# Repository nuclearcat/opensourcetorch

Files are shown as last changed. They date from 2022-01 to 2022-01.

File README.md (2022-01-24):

Opensource programmable... torch? light? flashlight? I dont know, but it is funny and i like it.

We have onboard:
3xRGB(parallel) light, indicator light, accelerometer, illumination sensor, USB-Serial (CH340) for debug, lithium battery charger.

Example applications: coming soon

Read ERRATA first, if you want to make your own!

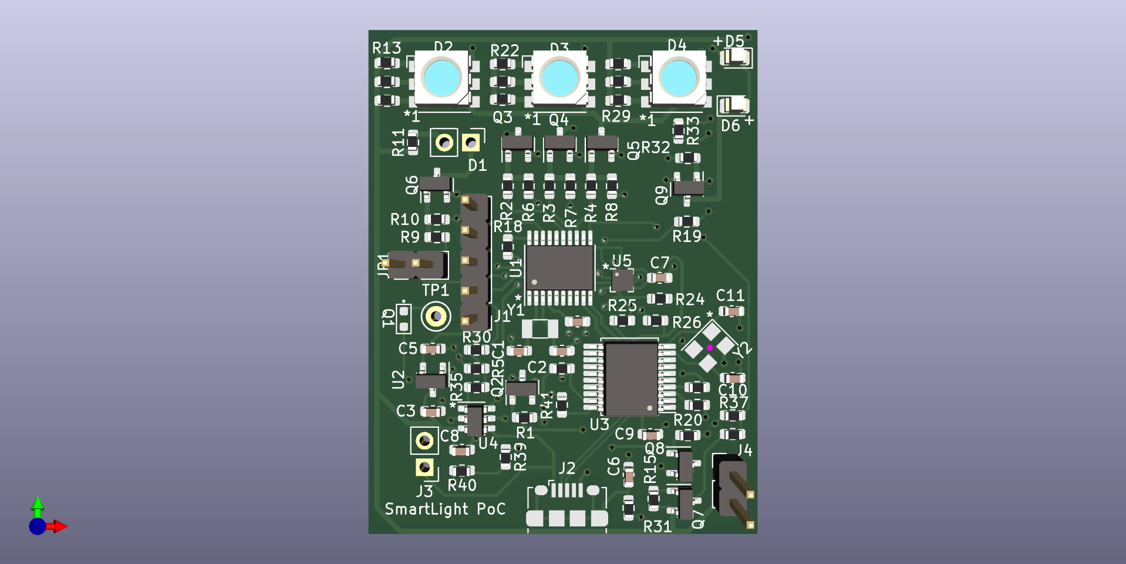
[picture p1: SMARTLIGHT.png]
v1 prototype


ERRATA in v1.0   
* 32Khz oscillator on MCU not starting reliably. (Might be software issue.)

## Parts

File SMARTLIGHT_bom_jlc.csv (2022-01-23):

Comment | Designator | Footprint | LCSC Part #
15pf | C1,C2,C6 | C_0603_1608Metric | C1644
1u | C3,C4,C5,C7,C9 | C_0603_1608Metric | C15849
10u | C8 | C_0603_1608Metric | C19702
12p | C10,C11 | C_0603_1608Metric | C38523
MHP5050RGBDT | D2,D3,D4 | MHP5050RGBDT | C409780
RED | D5,D6 | LED_0805_2012Metric | C138549
USB_B_Micro | J2 | USB_Micro-B_Amphenol_10118194_Horizontal | C132563
ALS-PT19 | Q1 | ALS-PT19 | C146233
YJL3400A | Q2,Q3,Q4,Q5,Q6,Q8,Q9 | SOT-23 | C699302
AO3401A | Q7 | SOT-23 | C15127
10k | R1,R5,R6,R7,R8,R10,R15,R16,R17,R20,R25,R26,R30,R31,R32,R34,R35,R39,R41 | R_0603_1608Metric | C25804
100 | R2,R3,R4,R9,R18,R19,R37,R38 | R_0603_1608Metric | C22775
10 | R11,R12,R13,R14,R21,R22,R23,R27,R28,R29,R33 | R_0603_1608Metric | C22859
0 | R40 | R_0603_1608Metric | C21189
STM32G030F6Px | U1 | TSSOP-20_4.4x6.5mm_P0.65mm | C529330
XC6206P332MR | U2 | SOT-23 | C5446
CH340T | U3 | SSOP-20_5.3x7.2mm_P0.65mm | C8689
FM4057S42 | U4 | SOT-23-6 | C841287
KX022-1020 | U5 | LGA-12_2x2mm_P0.5mm | C694095
Crystal | Y1 | Crystal_SMD_3215-2Pin_3.2x1.5mm | C32346
X322512MSB4SI | Y2 | Oscillator_SMD_SeikoEpson_SG8002CE-4Pin_3.2x2.5mm | C9002

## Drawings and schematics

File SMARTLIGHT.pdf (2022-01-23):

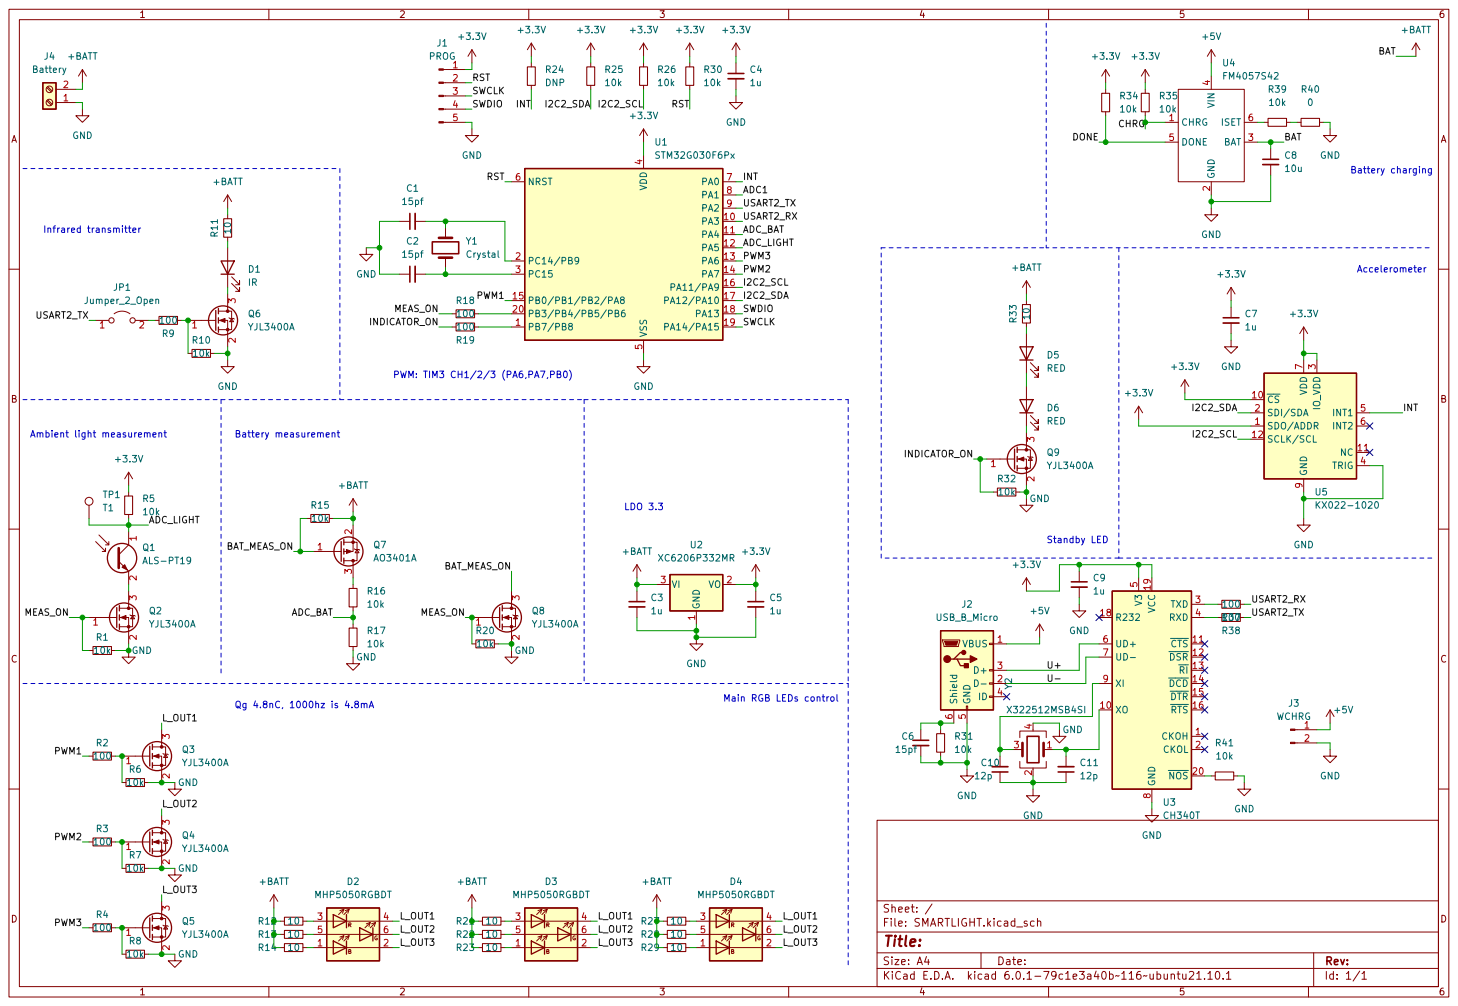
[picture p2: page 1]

1 VO 2 VI 3 U2 XC6206P332MR GND GND

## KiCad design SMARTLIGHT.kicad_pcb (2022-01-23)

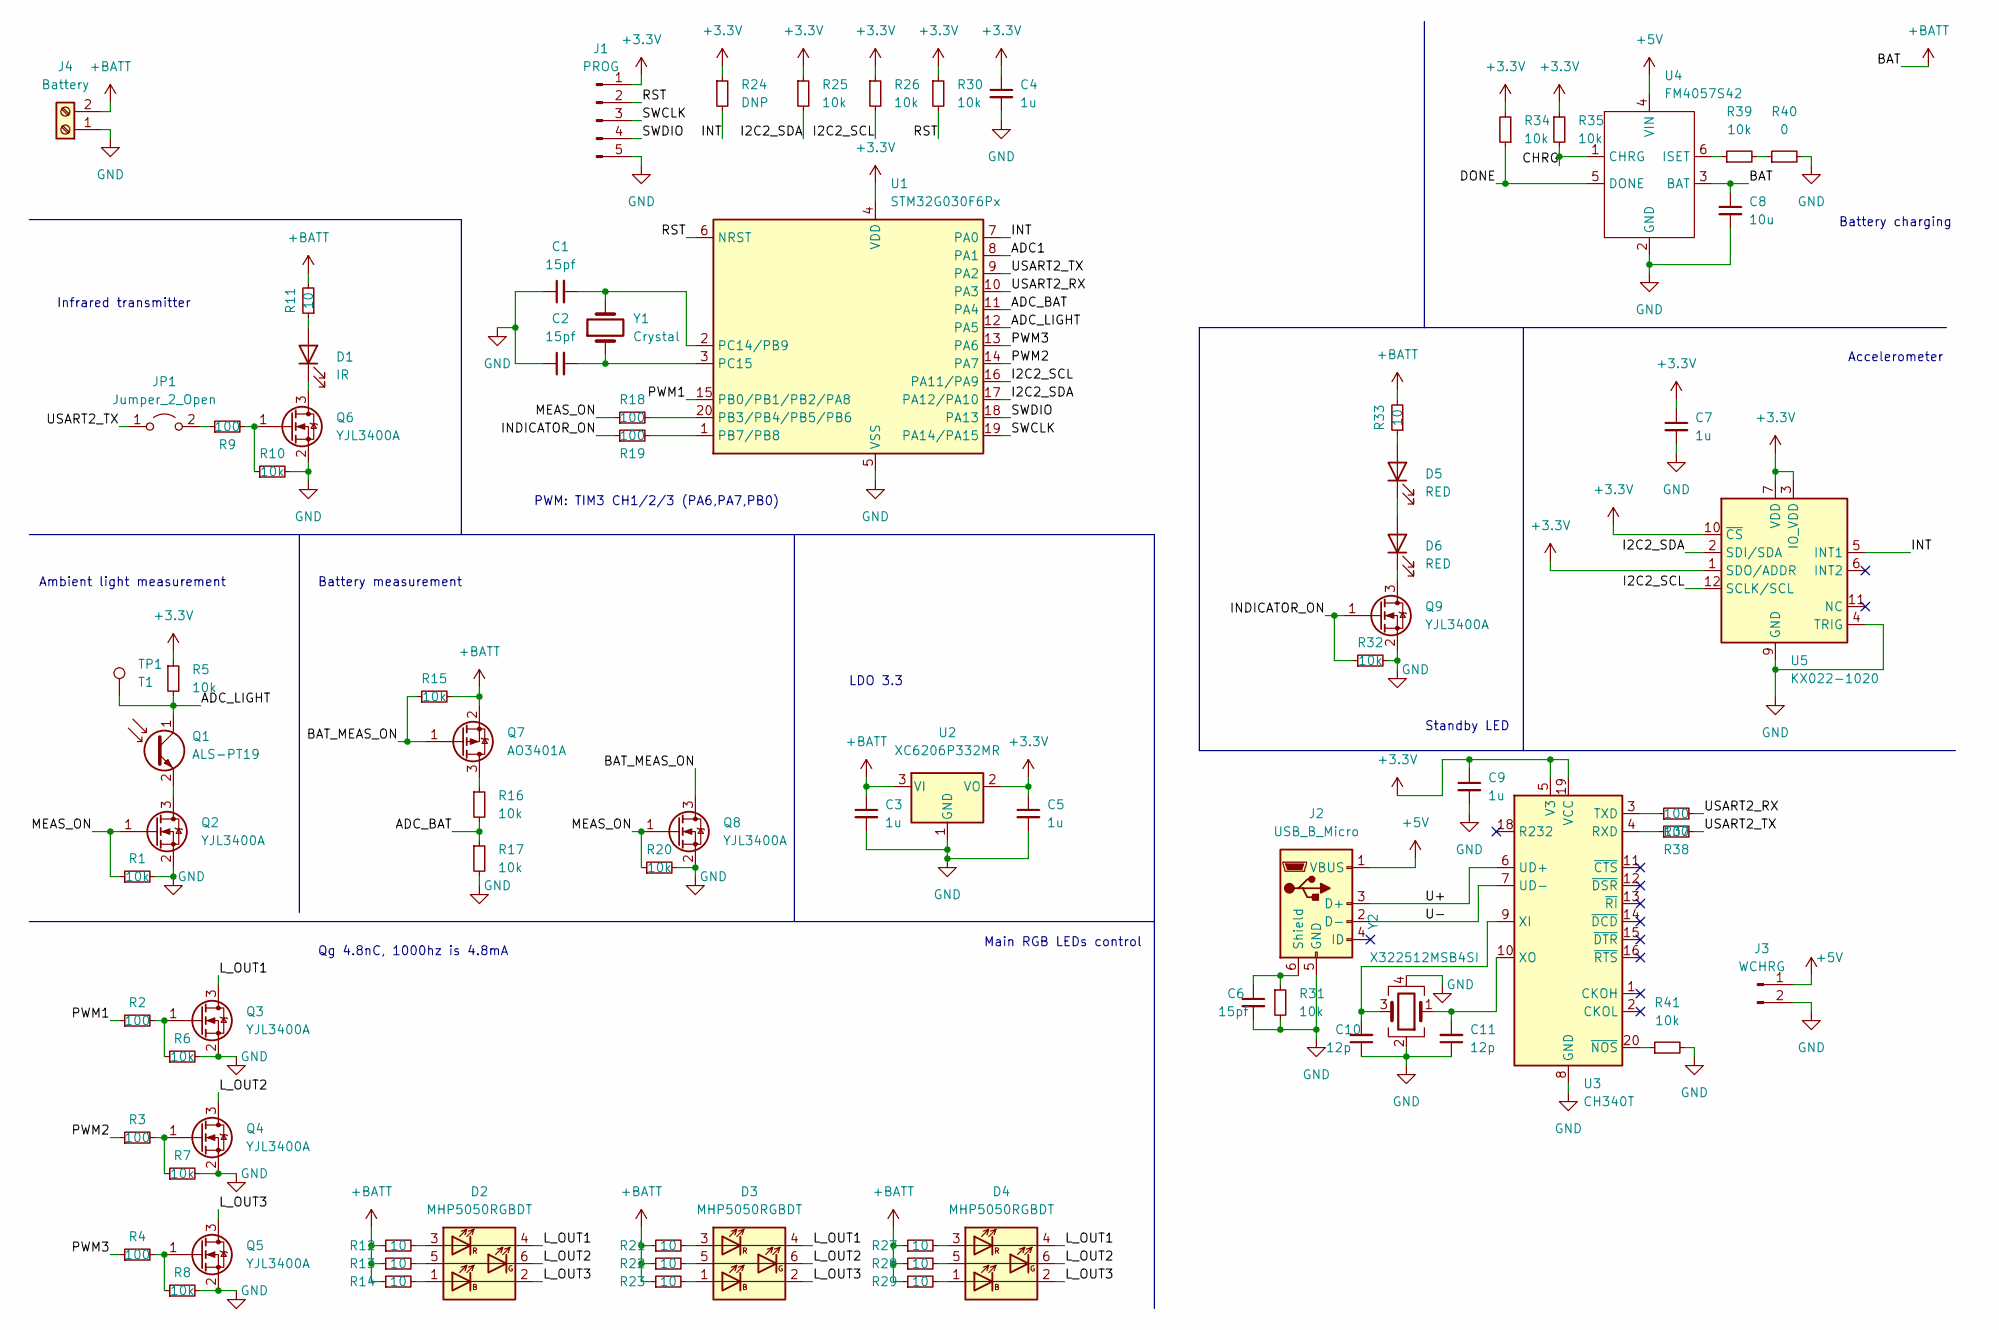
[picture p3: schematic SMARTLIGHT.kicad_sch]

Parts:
C1, C2, C6: 15pf; C_0603_1608Metric; LCSC PN C1644
C3, C4, C5, C7, C9: 1u; C_0603_1608Metric; LCSC PN C15849
C8: 10u; C_0603_1608Metric; LCSC PN C19702
C10, C11: 12p; C_0603_1608Metric; LCSC PN C38523
D1: IR; PinHeader_1x02_P2.54mm_Vertical
D2, D3, D4: MHP5050RGBDT; LCSC PN C409780
D5, D6: RED; LED_0805_2012Metric; LCSC PN C138549
J1: PROG; PinHeader_1x05_P2.54mm_Vertical
J2: USB_B_Micro; USB_Micro-B_Amphenol_10118194_Horizontal; LCSC PN C132563
J3: WCHRG; PinHeader_1x02_P2.54mm_Vertical
J4: Battery; PinHeader_1x02_P2.54mm_Vertical
JP1: Jumper_2_Open; PinHeader_1x02_P2.54mm_Vertical
Q1: ALS-PT19; LCSC PN C146233
Q2, Q3, Q4, Q5, Q6, Q8, Q9: YJL3400A; SOT-23; LCSC PN C699302
Q7: AO3401A; SOT-23; LCSC PN C15127
R1, R5, R6, R7, R8, R10, R15, R16, R17, R20, R25, R26, R30, R31, R32, R34, R35, R39, R41: 10k; R_0603_1608Metric; LCSC PN C25804
R2, R3, R4, R9, R18, R19, R37, R38: 100; R_0603_1608Metric; LCSC PN C22775
R11, R12, R13, R14, R21, R22, R23, R27, R28, R29, R33: 10; R_0603_1608Metric; LCSC PN C22859
R24: DNP; R_0603_1608Metric
R40: 0; R_0603_1608Metric; LCSC PN C21189
TP1: T1; TestPoint_Keystone_5000-5004_Miniature
U1: STM32G030F6Px; TSSOP-20_4.4x6.5mm_P0.65mm; LCSC PN C529330
U2: XC6206P332MR; SOT-23; LCSC PN C5446
U3: CH340T; SSOP-20_5.3x7.2mm_P0.65mm; LCSC PN C8689
U4: FM4057S42; SOT-23-6; LCSC PN C841287
U5: KX022-1020; LGA-12_2x2mm_P0.5mm; LCSC PN C694095
Y1: Crystal; Crystal_SMD_3215-2Pin_3.2x1.5mm; LCSC PN C32346
Y2: X322512MSB4SI; Oscillator_SMD_SeikoEpson_SG8002CE-4Pin_3.2x2.5mm; LCSC PN C9002

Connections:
+3V3: C4.1, C5.1, C7.1, C9.1, J1.1, R5.1, R24.1, R25.1, R26.1, R30.1, R34.2, R35.1, U1.4 (VDD), U2.2 (VO), U3.5 (V3), U3.19 (VCC), U5.1 (SDO/ADDR), U5.3 (IO_VDD), U5.7 (VDD), U5.10 (~CS)
+5V: J2.1 (VBUS), J3.1, U4.4 (VIN)
+BATT: C3.1, C8.1, J4.2, Q7.2 (S), R11.2, R12.1, R13.1, R14.1, R15.2, R21.1, R22.1, R23.1, R27.1, R28.1, R29.1, R33.2, U2.3 (VI), U4.3 (BAT)
/ADC1: U1.8 (PA1)
/ADC_BAT: R16.2, R17.1, U1.11 (PA4)
/ADC_LIGHT: Q1.1 (C), R5.2, TP1.1, U1.12 (PA5)
/BAT_MEAS_ON: Q7.1 (G), Q8.3 (D), R15.1
/CHRG: R35.2, U4.1 (CHRG)
/DONE: R34.1, U4.5 (DONE)
/I2C2_SCL: R26.2, U1.16 (PA11/PA9), U5.12 (SCLK/SCL)
/I2C2_SDA: R25.2, U1.17 (PA12/PA10), U5.2 (SDI/SDA)
/INDICATOR_ON: Q9.1 (G), R19.1, R32.1
/INT: R24.2, U1.7 (PA0), U5.5 (INT1)
/L_OUT1: D2.4 (KR), D3.4 (KR), D4.4 (KR), Q3.3 (D)
/L_OUT2: D2.6 (KR), D3.6 (KR), D4.6 (KR), Q4.3 (D)
/L_OUT3: D2.2 (KB), D3.2 (KB), D4.2 (KB), Q5.3 (D)
/MEAS_ON: Q2.1 (G), Q8.1 (G), R1.1, R18.1, R20.1
/PWM1: R2.1, U1.15 (PB0/PB1/PB2/PA8)
/PWM2: R3.1, U1.14 (PA7)
/PWM3: R4.1, U1.13 (PA6)
/RST: J1.2, R30.2, U1.6 (NRST)
/SWCLK: J1.3, U1.19 (PA14/PA15)
/SWDIO: J1.4, U1.18 (PA13)
/U+: J2.3 (D+), U3.6 (UD+)
/U-: J2.2 (D-), U3.7 (UD-)
/USART2_RX: R37.2, U1.10 (PA3)
/USART2_TX: JP1.1 (A), R38.2, U1.9 (PA2)
GND: C1.1, C2.1, C3.2, C4.2, C5.2, C6.2, C7.2, C8.2, C9.2, C10.1, C11.1, J1.5, J2.5 (GND), J3.2, J4.1, Q2.2 (S), Q3.2 (S), Q4.2 (S), Q5.2 (S), Q6.2 (S), Q8.2 (S), Q9.2 (S), R1.2, R6.2, R7.2, R8.2, R10.2, R17.2, R20.2, R31.2, R32.2, R40.2, R41.2, U1.5 (VSS), U2.1 (GND), U3.8 (GND), U4.2 (GND), U5.4 (TRIG), U5.8 (GND), U5.9 (GND), Y2.2, Y2.4
unnamed: C1.2, U1.2 (PC14/PB9), Y1.2
unnamed: C2.2, U1.3 (PC15), Y1.1
unnamed: C6.1, J2.6 (Shield), R31.1
unnamed: C10.2, U3.9 (XI), Y2.3
unnamed: C11.2, U3.10 (XO), Y2.1
unnamed: D1.1 (K), Q6.3 (D)
unnamed: D1.2 (A), R11.1
unnamed: D2.1 (AB), R14.2
unnamed: D2.3 (AR), R12.2
unnamed: D2.5 (AG), R13.2
unnamed: D3.1 (AB), R23.2
unnamed: D3.3 (AR), R21.2
unnamed: D3.5 (AG), R22.2
unnamed: D4.1 (AB), R29.2
unnamed: D4.3 (AR), R27.2
unnamed: D4.5 (AG), R28.2
unnamed: D5.1 (K), D6.2 (A)
unnamed: D5.2 (A), R33.1
unnamed: D6.1 (K), Q9.3 (D)
unnamed: JP1.2 (B), R9.1
unnamed: Q1.2 (E), Q2.3 (D)
unnamed: Q3.1 (G), R2.2, R6.1
unnamed: Q4.1 (G), R3.2, R7.1
unnamed: Q5.1 (G), R4.2, R8.1
unnamed: Q6.1 (G), R9.2, R10.1
unnamed: Q7.3 (D), R16.1
unnamed: R18.2, U1.20 (PB3/PB4/PB5/PB6)
unnamed: R19.2, U1.1 (PB7/PB8)
unnamed: R37.1, U3.3 (TXD)
unnamed: R38.1, U3.4 (RXD)
unnamed: R39.1, U4.6 (ISET)
unnamed: R39.2, R40.1
unnamed: R41.1, U3.20 (~NOS)

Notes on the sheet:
Ambient light measurement
Infrared transmitter
Accelerometer
Standby LED
PWM: TIM3 CH1/2/3 (PA6,PA7,PB0)
Battery measurement
Qg 4.8nC, 1000hz is 4.8mA
Battery charging
Main RGB LEDs control
LDO 3.3

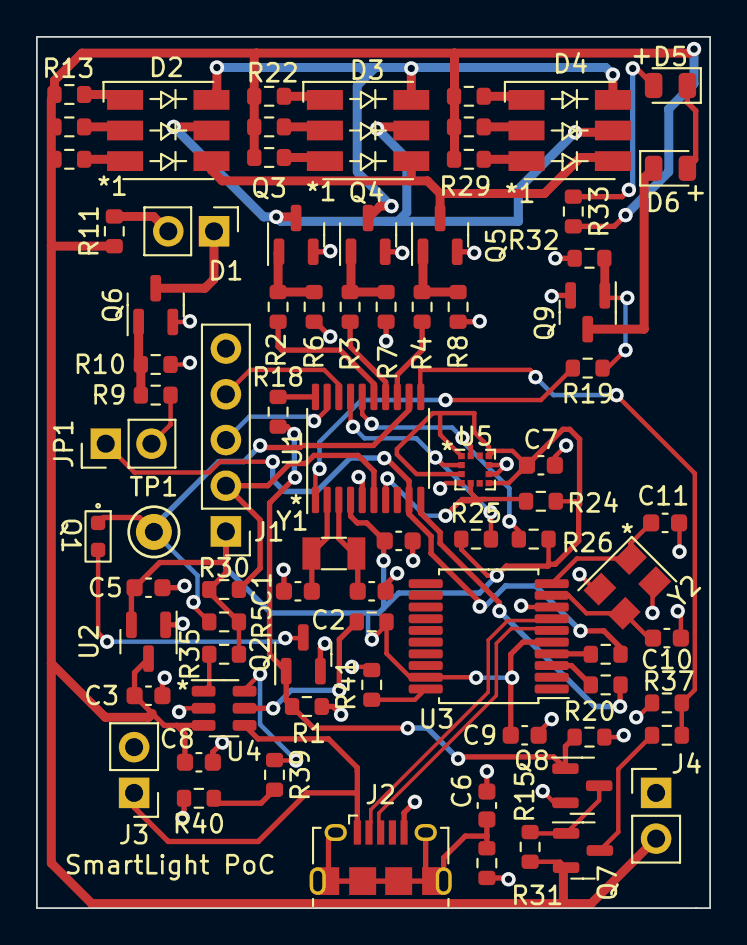
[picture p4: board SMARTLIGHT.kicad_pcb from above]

Board: 2 copper layers, 37.4 x 48.4 mm, 79 parts (0 on the bottom side), 60 nets.

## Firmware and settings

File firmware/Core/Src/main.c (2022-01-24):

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
/* Includes ------------------------------------------------------------------*/
#include "main.h"

ADC_HandleTypeDef hadc1;

I2C_HandleTypeDef hi2c2;

RTC_HandleTypeDef hrtc;

TIM_HandleTypeDef htim1;
TIM_HandleTypeDef htim3;

UART_HandleTypeDef huart2;

void SystemClock_Config(void);
static void MX_GPIO_Init(void);
static void MX_ADC1_Init(void);
static void MX_I2C2_Init(void);
static void MX_RTC_Init(void);
static void MX_USART2_UART_Init(void);
static void MX_TIM1_Init(void);
static void MX_TIM3_Init(void);
/* USER CODE BEGIN 0 */

int kx022_readregs(int addr, uint8_t * data, int len) {
  int status = HAL_I2C_Mem_Read(&hi2c2, KX022_I2C_ADDRESS, addr, I2C_MEMADD_SIZE_8BIT, data, len, 10000);
  if (status != HAL_OK)
    return 1;
  else
    return 0;
}

int kx022_writeregs(int addr, uint8_t * data, int len) {
  int status =  HAL_I2C_Mem_Write(&hi2c2, (uint16_t)KX022_I2C_ADDRESS, addr, I2C_MEMADD_SIZE_8BIT, (uint8_t *)data, len, 10000);
  if (status != HAL_OK)
    return 1;
  else
    return 0;
}

int16_t kx022_getAccAxis(uint8_t addr) {
    int16_t acc;
    uint8_t res[2];
 
    kx022_readregs(addr, res, 2);
    acc = ((res[1] << 8) | res[0]);
    return acc;
}

int16_t kx022_getAccX() {
    return (kx022_getAccAxis(KX022_XOUT_L));
}
 
int16_t kx022_getAccY() {
    return (kx022_getAccAxis(KX022_YOUT_L));
}
 
int16_t kx022_getAccZ() {
    return (kx022_getAccAxis(KX022_ZOUT_L));
}


void test_measure_light(void) {
  ADC_ChannelConfTypeDef sConfig = {0};
  char buffer[32] = { 0 };
  
  // Make sure other lights off to not interfere
  __HAL_TIM_SET_COMPARE(&htim3, TIM_CHANNEL_1, 0);
  __HAL_TIM_SET_COMPARE(&htim3, TIM_CHANNEL_2, 0);
  __HAL_TIM_SET_COMPARE(&htim3, TIM_CHANNEL_3, 0);

  // Power on measurement circuit (battery and light)
  HAL_GPIO_WritePin(MEAS_CTRL_PORT, MEAS_CTRL_PIN, GPIO_PIN_SET);
  // Delay to settle down
  HAL_Delay(1);

  sConfig.Channel = ADC_CHANNEL_5;
  sConfig.Rank = ADC_REGULAR_RANK_1;
  sConfig.SamplingTime = ADC_SAMPLETIME_7CYCLES_5;
  if (HAL_ADC_ConfigChannel(&hadc1, &sConfig) != HAL_OK)
  {
    Error_Handler();
  }
  
  if (HAL_ADC_Start(&hadc1) != HAL_OK) { Error_Handler(); }
  if (HAL_ADC_PollForConversion(&hadc1, 10) != HAL_OK) { Error_Handler(); }
  uint16_t uhADCxConvertedValue = HAL_ADC_GetValue(&hadc1);
  HAL_GPIO_WritePin(MEAS_CTRL_PORT, MEAS_CTRL_PIN, GPIO_PIN_RESET);

  sprintf(buffer, "LIGHT %d\r\n", uhADCxConvertedValue);
  HAL_UART_Transmit(&huart2, buffer, sizeof(buffer), HAL_MAX_DELAY);
}

void test_accelerometer(void) {
    char buffer[32] = { 0 };
    int32_t accx = kx022_getAccX();
    int32_t accy = kx022_getAccY();
    int32_t accz = kx022_getAccZ();

    sprintf(buffer, "X/Y/Z %ld/%ld/%ld\r\n", accx, accy, accz);
    HAL_UART_Transmit(&huart2, buffer, sizeof(buffer), HAL_MAX_DELAY);
    HAL_Delay(1);
}

void feature_light_down(void) {
    int32_t accx = kx022_getAccX();
    int32_t accy = kx022_getAccY();
    int32_t accz = kx022_getAccZ();
    int32_t absx;
    if (accx < 0)
        absx = accx * -1;
    else
        absx = accx;
    

    if (accz < -10000 && absx < 10000) {
         __HAL_TIM_SET_COMPARE(&htim3, TIM_CHANNEL_1, 700);
         __HAL_TIM_SET_COMPARE(&htim3, TIM_CHANNEL_2, 700);
         __HAL_TIM_SET_COMPARE(&htim3, TIM_CHANNEL_3, 700);
    } else {
         __HAL_TIM_SET_COMPARE(&htim3, TIM_CHANNEL_1, 0);
         __HAL_TIM_SET_COMPARE(&htim3, TIM_CHANNEL_2, 0);
         __HAL_TIM_SET_COMPARE(&htim3, TIM_CHANNEL_3, 0);
    }



}

/*
void police() {
    for (int i=0; i<5; i++) {
      HAL_Delay(50);
      __HAL_TIM_SET_COMPARE(&htim3, TIM_CHANNEL_1, 0); //blue
      HAL_Delay(50);
      __HAL_TIM_SET_COMPARE(&htim3, TIM_CHANNEL_1, 90); //blue
    }
    __HAL_TIM_SET_COMPARE(&htim3, TIM_CHANNEL_1, 0); //blue
    
    for (int i=0; i<5; i++) {
      HAL_Delay(50);
      __HAL_TIM_SET_COMPARE(&htim3, TIM_CHANNEL_2, 0);
      HAL_Delay(50);
      __HAL_TIM_SET_COMPARE(&htim3, TIM_CHANNEL_2, 90);
    }
    
    __HAL_TIM_SET_COMPARE(&htim3, TIM_CHANNEL_2, 0);
}
*/
#define GRADUAL_MAXBRI 600
void test_slow_glow() {
  for (int i=0; i<GRADUAL_MAXBRI; i++) {
    HAL_Delay(5);
    __HAL_TIM_SET_COMPARE(&htim3, TIM_CHANNEL_1, i);
    __HAL_TIM_SET_COMPARE(&htim3, TIM_CHANNEL_2, i);
    __HAL_TIM_SET_COMPARE(&htim3, TIM_CHANNEL_3, i);
  }
  for (int i=0; i<GRADUAL_MAXBRI; i++) {
    HAL_Delay(5);
    __HAL_TIM_SET_COMPARE(&htim3, TIM_CHANNEL_1, GRADUAL_MAXBRI-i);
    __HAL_TIM_SET_COMPARE(&htim3, TIM_CHANNEL_2, GRADUAL_MAXBRI-i);
    __HAL_TIM_SET_COMPARE(&htim3, TIM_CHANNEL_3, GRADUAL_MAXBRI-i);
    
  }
}



void accel_start() {
    unsigned char buf = 0x0;
    unsigned char reg[2];

    int ret = kx022_readregs(KX022_WHO_AM_I, &buf, sizeof(buf));
    if (ret || buf != KX022_WAI_VAL) {
        __HAL_TIM_SET_COMPARE(&htim3, TIM_CHANNEL_2, 1); //red
    }
    
    reg[0] = 0x41;
    kx022_writeregs(KX022_CNTL1, reg, 1);

    //reg[0] = 0x02;
    reg[0] = 0x06; //800hz
    kx022_writeregs(KX022_ODCNTL, reg, 1);

    reg[0] = 0xD8;
    kx022_writeregs(KX022_CNTL3, reg, 1);

    reg[0] = 0x01;
    kx022_writeregs(KX022_TILT_TIMER, reg, 1);

    reg[0] = 0xC1;
    kx022_writeregs(KX022_CNTL1, reg, 1);
    
}

/**
  * @brief  The application entry point.
  * @retval int
  */
int main(void)
{
  HAL_Init();
  SystemClock_Config();
  MX_GPIO_Init();
  //HAL_GPIO_WritePin(GPIOB, GPIO_PIN_7, GPIO_PIN_SET);
  //HAL_Delay(1000);
  //HAL_GPIO_WritePin(GPIOB, GPIO_PIN_7, GPIO_PIN_RESET);
  MX_ADC1_Init();
  MX_I2C2_Init();
  //MX_RTC_Init();
  MX_USART2_UART_Init();
  MX_TIM1_Init();
  MX_TIM3_Init();

  // Force all LED to off
  __HAL_TIM_SET_COMPARE(&htim3, TIM_CHANNEL_1, 0); //blue
  __HAL_TIM_SET_COMPARE(&htim3, TIM_CHANNEL_2, 0); //red
  __HAL_TIM_SET_COMPARE(&htim3, TIM_CHANNEL_3, 0); //green
  accel_start();

  HAL_UART_Transmit(&huart2, "BOOT\r\n", 6, HAL_MAX_DELAY);
// Test/debug illumination sensor
#if 0
  while (1) { test_measure_light(); }
#endif

// Test/debug accelerometer
#if 0
  while (1) { test_accelerometer(); }
#endif

// Test: slow glow (brightness change)
//#if 0
  while (1) { test_slow_glow(); }
//#endif


// Feature: turn on RGB light only when light looks downwards
#if 0
  while (1) { feature_light_down(); }
#endif

  while (1)
  {
    //float accx = kx022_getAccX();
    //float accy = kx022_getAccY();
    //float accz = kx022_getAccZ();
    /*
    if (accx != 0.0) {
      if (test) {
        __HAL_TIM_SET_COMPARE(&htim3, TIM_CHANNEL_2, 1); //red
        __HAL_TIM_SET_COMPARE(&htim3, TIM_CHANNEL_3, 0); //green
        test=0;
      } else {
        __HAL_TIM_SET_COMPARE(&htim3, TIM_CHANNEL_2, 0); //red
        __HAL_TIM_SET_COMPARE(&htim3, TIM_CHANNEL_3, 1); //green
        test=1;
      }
    }
    
    
    if (accx > 0) {
      __HAL_TIM_SET_COMPARE(&htim3, TIM_CHANNEL_1, (int)(accx*10.0));
    } else {
      __HAL_TIM_SET_COMPARE(&htim3, TIM_CHANNEL_1, (int)(accx*-10.0));
    }
    if (accy > 0) {
      __HAL_TIM_SET_COMPARE(&htim3, TIM_CHANNEL_2, (int)(accy*10.0));
    } else {
      __HAL_TIM_SET_COMPARE(&htim3, TIM_CHANNEL_2, (int)(accy*-10.0));
    }
    if (accz > 0) {
      __HAL_TIM_SET_COMPARE(&htim3, TIM_CHANNEL_3, (int)(accz*10.0));
    } else {
      __HAL_TIM_SET_COMPARE(&htim3, TIM_CHANNEL_3, (int)(accz*-10.0));
    }
    */

    //gradual();
    // Measure light
    //meas_light();
    //HAL_Delay(250);
    //HAL_GPIO_TogglePin(GPIOB, GPIO_PIN_7);
    
    //police();
    /* USER CODE END WHILE */
    //HAL_GPIO_WritePin(GPIOB, GPIO_PIN_7, GPIO_PIN_SET);
    /* USER CODE BEGIN 3 */
  }
  /* USER CODE END 3 */
}

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


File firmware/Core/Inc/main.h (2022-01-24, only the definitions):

#define INDICATOR_PIN           GPIO_PIN_7
#define INDICATOR_PORT          GPIOB
#define MEAS_CTRL_PIN           GPIO_PIN_3
#define MEAS_CTRL_PORT          GPIOB
#define KX022_I2C_ADDRESS     (0x1F << 1)
#define KX022_WAI_VAL         (0x14)
#define KX022_XOUT_L          (0x06)
#define KX022_XOUT_H          (0x07)
#define KX022_YOUT_L          (0x08)
#define KX022_YOUT_H          (0x09)
#define KX022_ZOUT_L          (0x0A)
#define KX022_ZOUT_H          (0x0B)
#define KX022_WHO_AM_I        (0x0F)
#define KX022_CNTL1           (0x18)
#define KX022_CNTL3           (0x1A)
#define KX022_ODCNTL          (0x1B)
#define KX022_TILT_TIMER      (0x22)

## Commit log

2022-01-23 Sample code to run
2022-01-23 Accelerometer check

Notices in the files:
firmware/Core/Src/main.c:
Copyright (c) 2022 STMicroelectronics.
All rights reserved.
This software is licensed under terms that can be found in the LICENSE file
